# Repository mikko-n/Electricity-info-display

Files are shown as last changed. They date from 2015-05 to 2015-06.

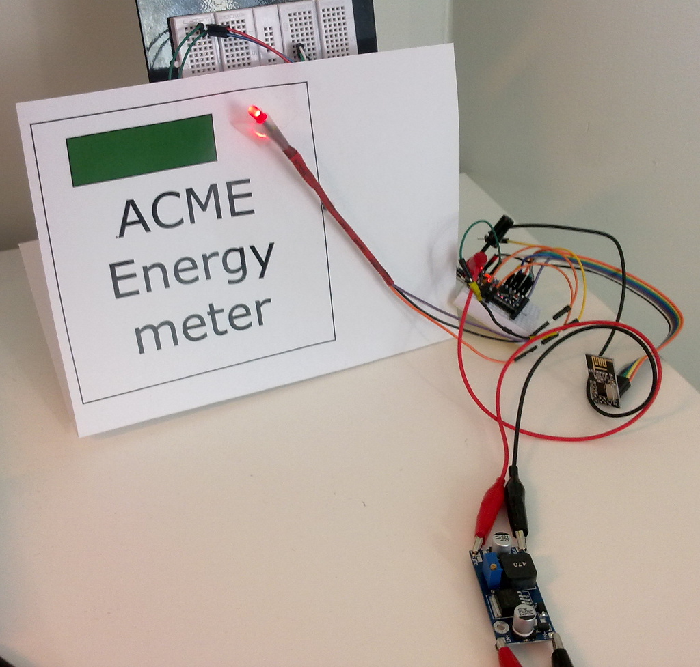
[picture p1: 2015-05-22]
material/valmis2.jpg

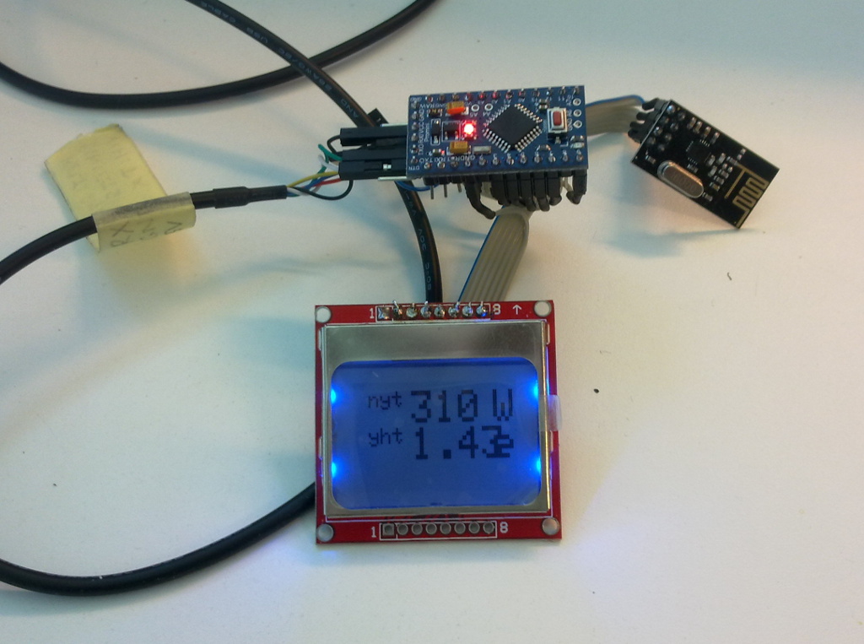
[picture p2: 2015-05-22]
material/valmis3.jpg

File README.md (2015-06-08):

# Electricity-info-display
Simple RF Electricity info display with Arduinos, radios &amp; mandatory LED

![Display device] (/material/valmis3.jpg)

Creation from Nortal Hackathon 2015 event.

### Motivation
Without easily accessible and real-time measurement data the training process for living in our new house in the most paycheck-friendly way would be slow and based mostly on guesswork. To help ourselves to learn more quickly, I created a "training wheels" device which would tell us what is happening right now, energy-wise.

### Known bugs
- Cumulative wattage counter overflows (an int value)
- If display unit is not receiving anything, it keeps displaying the previous values instead of nothing (or err msg)

### Further development ideas
 list of "additional things to try" still includes some ideas:

-  Web / mobile interface for visualizing the spendings / consumed watts
-  REST API for the data stream(s)
-  Add real-time clocks / additional sensors / nodes (=mesh network)
-  Sleep mode for battery powered nodes
-  Add audio warnings for certain events: used kw/h limit or dramatic changes in electricity consumption, for example
-  Pull spot prices for electricity from internet and give suggestions when it's cheap to do laundry (and change your electricity plan to use the spot pricing)
-  Profile your appliances and find/weed out the most energy hungry ones
-  Profile your appliances and send a notification when your laundry / dishes / etc are done (electricity consumption drops)

### Inspiration
- Geo Solo II smart energy monitor (http://www.greenenergyoptions.co.uk/products-and-services/products/solo-2/)
- Emoncms.org Open source energy visualization (http://emoncms.org/site/home)
- EmonGLCD (http://openenergymonitor.org/emon/emonglcd)
- IoT + DIY = http://www.mysensors.org/
- Über Home automation with Arduino & RasPi (http://www.instructables.com/id/Uber-Home-Automation-w-Arduino-Pi/)
- http://en.wikipedia.org/wiki/Acme_Corporation
- https://learn.adafruit.com/nokia-5110-3310-monochrome-lcd/wiring
- http://serdisplib.sourceforge.net/ser/pcd8544.html
- https://maniacbug.wordpress.com/2012/03/30/rf24network/

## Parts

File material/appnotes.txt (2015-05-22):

1. How to Program pro mini 3.3v with arduino nano
	-https://forum.sparkfun.com/viewtopic.php?f=32&t=27960
	-see nano-promini-programmer_bb.png for working connections
	
Nano---------------Pro Mini
3.3v-----------------------VCC
GND------------------------GND
Digital Pin 11(MOSI)----pin 11 (MOSI)
Digital Pin 12(MISO)----pin 12 (MISO)
Digital Pin 13(SCK)-----pin 13 (SCK)
Digital Pin 10----------RST	

2. make radios talk together (rf24 lib)

https://maniacbug.wordpress.com/2011/11/02/getting-started-rf24/

3. integrate ldr

4. display

There were some problems with the silkscreen, see following link for checking your display module type:

Nokia 5110 PCD8544 type 2 (http://serdisplib.sourceforge.net/ser/pcd8544.html)

              RES  CS  D/C  SI/DIN  CLK  VCC  LED  GND
display pin    1    2   3     4      5    6    7    8
arduino pin    3    4   5     6      7   3v3   6   GND

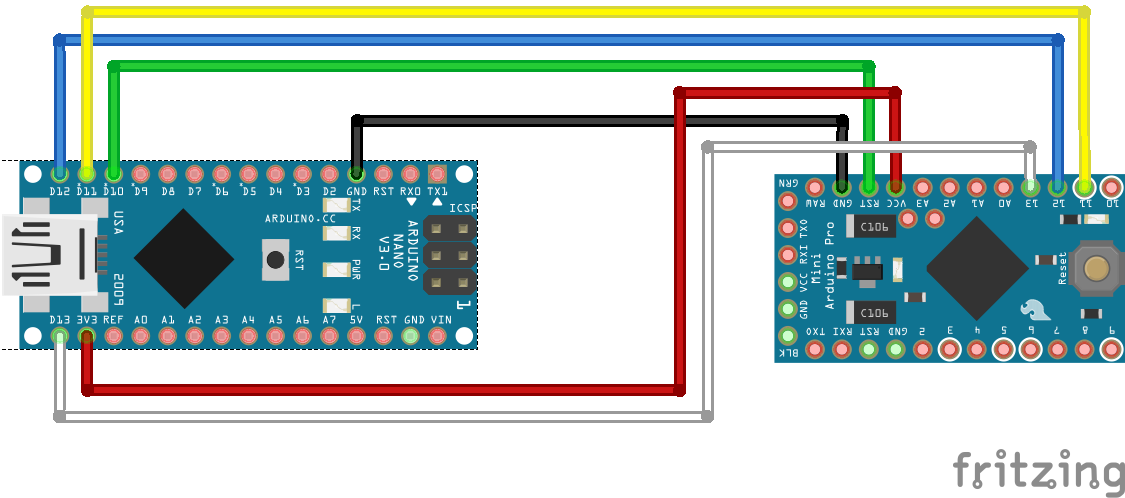
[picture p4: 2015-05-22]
material/nano-promini-programmer_bb.png

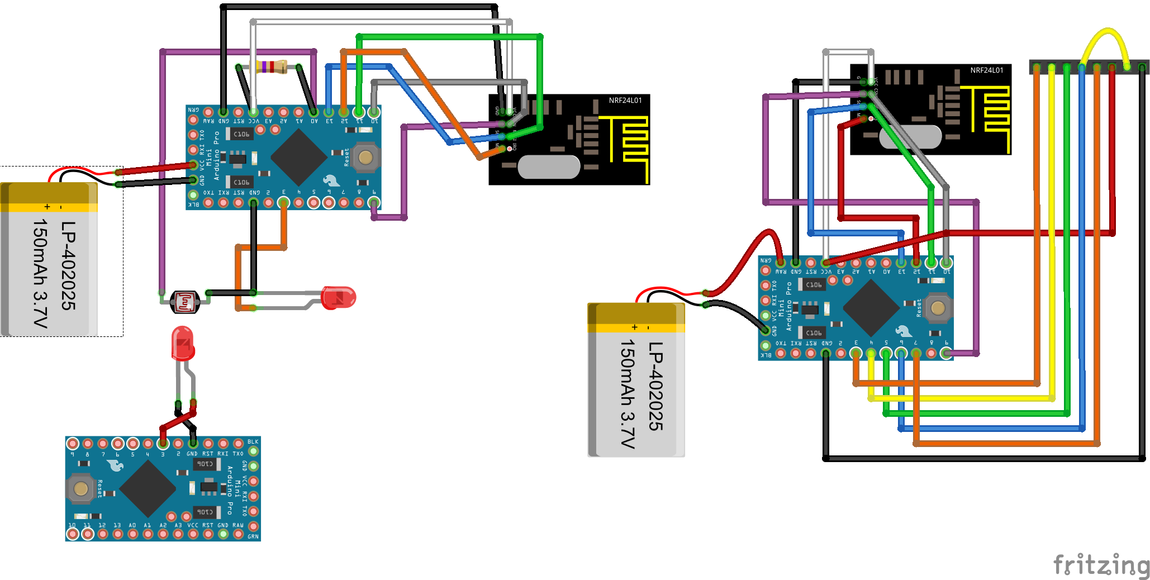
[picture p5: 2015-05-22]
material/kytkennät_bb.png

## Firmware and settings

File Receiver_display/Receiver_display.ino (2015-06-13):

/*
* Based on several tutorials & getting started example sketch for nRF24L01+ radios
*
* Firmware for Energy meter infodisplay unit, using
* Arduino Pro Mini, Nokia 5110 display & nRF24L01 radio
*/

#include <SPI.h>
#include "RF24.h"
#include <Adafruit_GFX.h>
#include <Adafruit_PCD8544.h>

// Software SPI (slower updates, more flexible pin options):
// pin 7 - Serial clock out (SCLK)
// pin 6 - Serial data out (DIN)
// pin 5 - Data/Command select (D/C)
// pin 4 - LCD chip select (CS)
// pin 3 - LCD reset (RST)
Adafruit_PCD8544 display = Adafruit_PCD8544(7, 6, 5, 4, 3);


/****************** User Config ***************************/
/***      Set this radio as radio number 0 or 1         ***/
bool radioNumber = 0;

/* Hardware configuration: Set up nRF24L01 radio on SPI bus plus pins 9 & 10 */
RF24 radio(9,10);
/**********************************************************/

byte addresses[][6] = {"1Node","2Node"};

// Used to control whether this node is sending (0) or receiving (1) 
// with two radios and just one-direction messaging, this could be !radioNumber
bool role = 1;

// data struct, changes here require an update to the receiver sketch, too
// note: sending 'String' type values does not work as intended, maybe a byte array should be used?
struct dataStruct{
	unsigned long _millis; // request timestamp
	String sender; // sending node id
	String receiver; // to who this packet is intended to
	unsigned int currentWatts;
	unsigned int cumulative_kW; // cumulative values divided to kW / W
	unsigned int cumulative_W;  // otherwise they will overflow quite quickly
	
} myData;

// price per kwh, from energy company
float price_per_kwh = 0.11f;

void setup() {
  Serial.begin(57600);
  display.begin();
  
  // Info display splash screen
  // There's an adafruit logo in the library, this could perhaps be sliced off if available memory is an issue
  display.clearDisplay(); // clear the display immediately to prevent AF logo showing up
  display.display(); // push blank screen to display
  display.setContrast(60); // range from 0-127
  display.setTextSize(2); // 1 is small, 2 for large
  display.setTextColor(BLACK);
  display.setCursor(0,0);
  display.println("Hackathon 2015");
  display.display();
  delay(2000);
  
  Serial.println(F("*** Receiving from the other node"));
  
  initRadio();
}

// radio initialization
void initRadio() {
  radio.begin();

  // Set the PA Level below maximum to prevent power supply related issues. Soldering a small cap between
  // the modules GND/Vin could help if those appear (do an internet search for solutions).
  // Because the close proximity of the devices, no need to use RF24_PA_MAX, which is default.
  // Available options are: RF24_PA_MIN, RF24_PA_LOW, RF24_PA_HIGH, RF24_PA_MAX
  // So far no problems.
  radio.setPALevel(RF24_PA_HIGH);
  
  // Open a writing and reading pipe on each radio, with opposite addresses
  if(radioNumber){
    radio.openWritingPipe(addresses[1]);
    radio.openReadingPipe(1,addresses[0]);
  }else{
    radio.openWritingPipe(addresses[0]);
    radio.openReadingPipe(1,addresses[1]);
  }
  
  // Start the radio listening for data
  radio.startListening();
}

void loop() {
  readValues();
   
}

// do the radio stuff
void readValues() {
/****************** Ping Out Role ***************************/  
if (role == 1)  {
    
    radio.stopListening();                                    // First, stop listening so we can talk.
        
    Serial.println(F("Sending request..."));

    unsigned long time = millis();                             // Take the time, and send it.  This will block until complete
     if (!radio.write( &time, sizeof(unsigned long) )){
       //Serial.println(F("failed"));
     }
        
    radio.startListening();                                    // Now, continue listening
    
    unsigned long started_waiting_at = millis();               // Set up a timeout period, get the current microseconds
    boolean timeout = false;                                   // Set up a variable to indicate if a response was received or not
    
    while ( ! radio.available() ){                             // While nothing is received
      if (micros() - started_waiting_at > 200000 ){            // If waited longer than 200ms, indicate timeout and exit while loop
          timeout = true;
          break;
      }      
    }
        
    if ( timeout ){                                             // Describe the results
        //Serial.println(F("Failed, response timed out."));
    } else {
        unsigned long got_time;                                // Grab the response, compare, and send to debug print
     
        radio.read( &myData, sizeof(myData) );

        doInfoDisplay();         

        // What have we here?
        Serial.print(F("Sent :"));
        Serial.print(time);
        Serial.print(F(", Got response from:"));
        Serial.print(myData.sender);
        Serial.print(", to: ");
        Serial.print(myData.receiver);
        Serial.print(", requested at: ");
        Serial.print(myData._millis);  
        Serial.print(", current kWh = ");
        Serial.print((double)myData.currentWatts);
        Serial.print(", cumulative W = ");
		Serial.print(myData.cumulative_kW);
		Serial.print(" ");
        Serial.println(myData.cumulative_W); 
        Serial.print(F(". Round-trip delay "));
        Serial.print(millis()-got_time);
        Serial.println(F(" milliseconds"));
    }

    // Try again 1s later
    delay(1000);
  }

} // readValues

// method to print info to display
void doInfoDisplay() {
  String currentWatts = "nyt"; // nyt = now/atm in finnish
  String yhteensa = "yht"; // yht = abbr for "total" in finnish
  
  display.clearDisplay();
  display.setTextSize(1); // height 7px
  display.setCursor(0,0);
  display.println(currentWatts);
  display.setCursor(0,16);
  display.println(yhteensa);
  
  // current consumption unit (kWh)
  display.setTextSize(2); // height 14px, width 10px
  display.setCursor(74,0); // 84(screen width)-10px
  display.println("W");
  display.setTextSize(1); // height 7px, width 5px
  display.setCursor(68,0); // 74-6px, see above
  display.println("k");
  display.setCursor(68,8); // 7px + 1px margin
  display.println("h");
  
  // total units
  display.setTextSize(1);
  display.setCursor(68,16); // x-axis, see above / y = 14px + 2px margin
  display.println("kW");
  display.setCursor(74,25);
  display.println("e");
    
  display.setCursor(24,0);
  display.setTextSize(2);
  if (myData.currentWatts > 0) {
     display.setTextSize(2);
     float current = (float)myData.currentWatts;      
     display.println((int)current);
  } else {    
     display.println('-');
  }
  
  display.setTextSize(1);
  display.setCursor(24,16);
  if (myData.cumulative_W > 0) {	 
	 // check the kW value for display purposes
	 if (myData.cumulative_kW > 0) {
		 float cumulative_kW =(float)myData.cumulative_kW; // do some typecasting just to look silly
		 display.print((int)cumulative_kW+"."); // and not to get random pointer values from struct printed out
	 } else {
		 display.print("0.");
	 }
	 
	 float cumulative_W = (float)myData.cumulative_W;
	 display.println((int)cumulative_W);
	      	 
     display.setCursor(24,25);
     float money = ((float)myData.cumulative_kW * 0.11f) + ((float)myData.cumulative_W * price_per_kwh / 1000.0f);
     display.println(money); 
  } else {     
     display.println('-');
     display.setCursor(24,25);
     display.println('-');
  }
  
  display.display();
}

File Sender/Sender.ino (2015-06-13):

/*
* Based on several tutorials & getting Started example sketch for nRF24L01+ radios
*
* Firmware for Energy meter interface unit (blink calculator) using
* Arduino Pro Mini, led, LDR & nRF24L01 radio
*/

#include <SPI.h>
#include "RF24.h"

/****************** User Config ***************************/
/***      Set this radio as radio number 0 or 1         ***/
bool radioNumber = 1;

/* Hardware configuration: Set up nRF24L01 radio on SPI bus plus pins 7 & 8 */
RF24 radio(9,10);
/**********************************************************/

byte addresses[][6] = {"1Node","2Node"};

// Used to control whether this node is sending (0) or receiving (1)
bool role = 0;

int led = 3; // measurement detected -led
int LDR = A0; // LDR pin
boolean isLedOn = false;
int ldrValue = 255;

// LDR threshold value, good start value is around 200 (bigger=more sensitive)
// As LDR is an analog device, this depends on your energy meter led pulse duration.
// Shorter pulses require more generous threshold value to be detected.
int ldrThreshold = 200;

unsigned long lastMeasurement = 0;

const float w_per_pulse = 1;  // watts consumed per led pulse
const unsigned long ms_per_hour = 3600000UL; // milliseconds in hour
unsigned int chan1_count = 0; // how many blinks are counted since started
unsigned long report_time = 0; // time since last report
unsigned long chan1_first_pulse = 0;
unsigned long chan1_last_pulse = 0;

//volatile byte chan1_pulse = 0; // for ISR function

// data struct, changes here require an update to the receiver sketch, too
// note: sending 'String' type values does not work as intended, maybe a byte array should be used?
struct dataStruct{
	unsigned long _millis; // request timestamp
	String sender; // sending node id
	String receiver; // to who this packet is intended to
	unsigned int currentWatts;
	unsigned int cumulative_kW; // cumulative values divided to kW / W
	unsigned int cumulative_W;  // otherwise they will overflow quite quickly
	
} myData;


void setup() {
	Serial.begin(57600);
	Serial.println(F("*** Sending to the other node"));
	
	pinMode(led, OUTPUT);
	pinMode(LDR, INPUT);
	myData.sender = "Wattmeter";
	myData.receiver = "Server";
	myData.currentWatts = 0;
	myData.cumulative_kW = 0;
	myData.cumulative_W = 0;
	radio.begin();

	// Set the PA Level below maximum to prevent power supply related issues. Soldering a small cap between
	// the modules GND/Vin could help if those appear (do an internet search for solutions)
	// Because the close proximity of the devices, no need to use RF24_PA_MAX, which is default.
	// Available options are: RF24_PA_MIN, RF24_PA_LOW, RF24_PA_HIGH, RF24_PA_MAX
	radio.setPALevel(RF24_PA_HIGH);
	
	// Open a writing and reading pipe on each radio, with opposite addresses
	if(radioNumber){
		radio.openWritingPipe(addresses[1]);
		radio.openReadingPipe(1,addresses[0]);
		}else{
		radio.openWritingPipe(addresses[0]);
		radio.openReadingPipe(1,addresses[1]);
	}
	
	// Start the radio listening for data
	radio.startListening();
}


// main loop, not much happens here
void loop() {
	
	doMeasurements();
	
}

// checks led, counts blinks, 1 blink = 1 watt
void doMeasurements() {
	
	unsigned long chan1_delta; // Time since last pulse
	static unsigned int chan1_watts; // current wattage
	
	// if 60 seconds since last detected pulse, current consumption = 0W
	if (millis() - chan1_last_pulse > 60000) {
		chan1_watts = 0;
	}
	
	// send reports in 5 second periods
	if (millis() - report_time > 5000) {
		
		// calculate time difference a.k.a time since last pulse
		chan1_delta = chan1_last_pulse - chan1_first_pulse;
		Serial.print("time (ms) pulse delta: ");
		Serial.println(chan1_delta);
		Serial.print("pulses counted since last report: ");
		Serial.println(chan1_count);
		
		
		if (chan1_delta != 0 && chan1_count != 0) {
						
			// calculate current W/h
			//             = (counted pulses - 1) * watts per pulse * ms in hour / time since last pulse
			chan1_watts = (chan1_count - 1) * w_per_pulse * ms_per_hour / chan1_delta;

			// current consumption calculated, reset counter
			chan1_count = 0;
			
			// put calculated value to data struct
			myData.currentWatts = chan1_watts;
		}
		
		// if current consumption and report time deviate from zero
		if (!(report_time == 0 && chan1_watts == 0)) {
			
			Serial.print("Current watts: ");
			Serial.println(chan1_watts);
			report_time = millis();
			
			reportValues();
			
		}
	}
	
	/*
	// should optimally come from ISR function
	if (chan1_pulse == 1) {
	chan1_count++;
	chan1_pulse = 0; // isLedOn

	chan1_last_pulse = millis();
	if (chan1_count == 1) { // was reset
	chan1_first_pulse = chan1_last_pulse;
	}
	}
	*/
	
	ldrValue = analogRead(LDR);

	if (ldrValue < ldrThreshold && !isLedOn) {
		Serial.print("LDR value = ");
		Serial.print(ldrValue);
		Serial.print(", led is ON again after ");
		Serial.print(millis()-lastMeasurement);
		Serial.println(" ms delay");
		isLedOn = true;
		digitalWrite(led, HIGH); // turn indicator led on
		
		myData.cumulative_W++;
		
		// check if kW counter should be updated
		if (myData.cumulative_W >= 1000) {
			myData.cumulative_kW++;
			myData.cumulative_W = 0;
		}
		
		lastMeasurement = millis();
	}
	else {
		if (isLedOn && ldrValue > ldrThreshold) {
			Serial.print("LDR value = ");
			Serial.print(ldrValue);
			Serial.println(", led turned OFF");
			isLedOn = false;
			digitalWrite(led, LOW); // turn indicator led on
			
			chan1_last_pulse = millis();
			chan1_count++;
			
			if (chan1_count == 1) { // was reset
				chan1_first_pulse = chan1_last_pulse;
			}
		}
	}
}

// do the radio stuff
void reportValues() {

	/****************** Pong Back Role (report readings on demand) ***************************/

	if ( role == 0 )
	{
		unsigned long got_time;
		//    static unsigned int chan1_watts;
		if( radio.available()){
			// Variable for the received timestamp
			while (radio.available()) {                                   // While there is data ready
				radio.read( &got_time, sizeof(unsigned long) );             // Get the payload
			}
			myData._millis = got_time;
			radio.stopListening();                                        // First, stop listening so we can talk
			radio.write( &myData, sizeof(myData) );                       // Send watt report
			radio.startListening();                                       // Now, resume listening so we catch the next packets.
			Serial.print(F("Sent response :"));
			
			Serial.print(myData._millis);
			Serial.print(", ");
			Serial.print(myData.currentWatts);
			Serial.print(", ");
			Serial.print(myData.cumulative_kW);
			Serial.print(", ");
			Serial.println(myData.cumulative_W);
		}
	}

} // reportValues()
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

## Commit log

2015-05-22 Code & additional material created during Nortal Hackathon 2015
    [kytkennät.fzz]
2015-06-08 Fixed bugs: - integer overflow bug in cumulative consumption - scale error in current consumption calculation
    Cleaning up done here and there.
    Code not tested yet (but hey, it's compiling!)
    [Receiver_display.ino, Sender.ino]
2015-06-13 Receiver sketch: -Fixed buffer overflow bug from struct pointer in display code -Display pixel adjustments
    Sender sketch:
    -Reformatted code in Sender.ino (diff broken)
    -Current kWh consumption math fixed
    [Receiver_display.ino, Sender.ino]
